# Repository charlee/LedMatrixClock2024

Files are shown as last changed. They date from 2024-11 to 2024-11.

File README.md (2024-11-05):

Led Matrix Clock 2024
=====================

## Hardware

This project is using the ESP32 MH-ET Live MiniKit board.

See [here](https://doc.riot-os.org/group__boards__esp32__mh-et-live-minikit.html) for the pin out of the board.

The hardware is a customized LED display with 3mm blue LEDs. The following diagram shows the layout (Q1..Q4 are the SN74HC595 chips).

```

  o o o o o   o o o o o         o o o o o   o o o o o | 2 \
  o o o o o   o o o o o   o o   o o o o o   o o o o o | 3  |
  o o o o o   o o o o o   o o   o o o o o   o o o o o | 4  |
  o o o o o   o o o o o         o o o o o   o o o o o | 5  | Q4
  o o o o o   o o o o o   o o   o o o o o   o o o o o | 6  |
  o o o o o   o o o o o   o o   o o o o o   o o o o o | 7  |
  o o o o o   o o o o o         o o o o o   o o o o o | 8 /
 -----------------------------------------------------+
  1 2 3 4 5   6 7 8 1 2   3 4   5 6 7 8 1   2 3 4 5 6
  `---------------' `-----------------' `-----------'
        Q1                  Q2                Q3

```

## Schematic

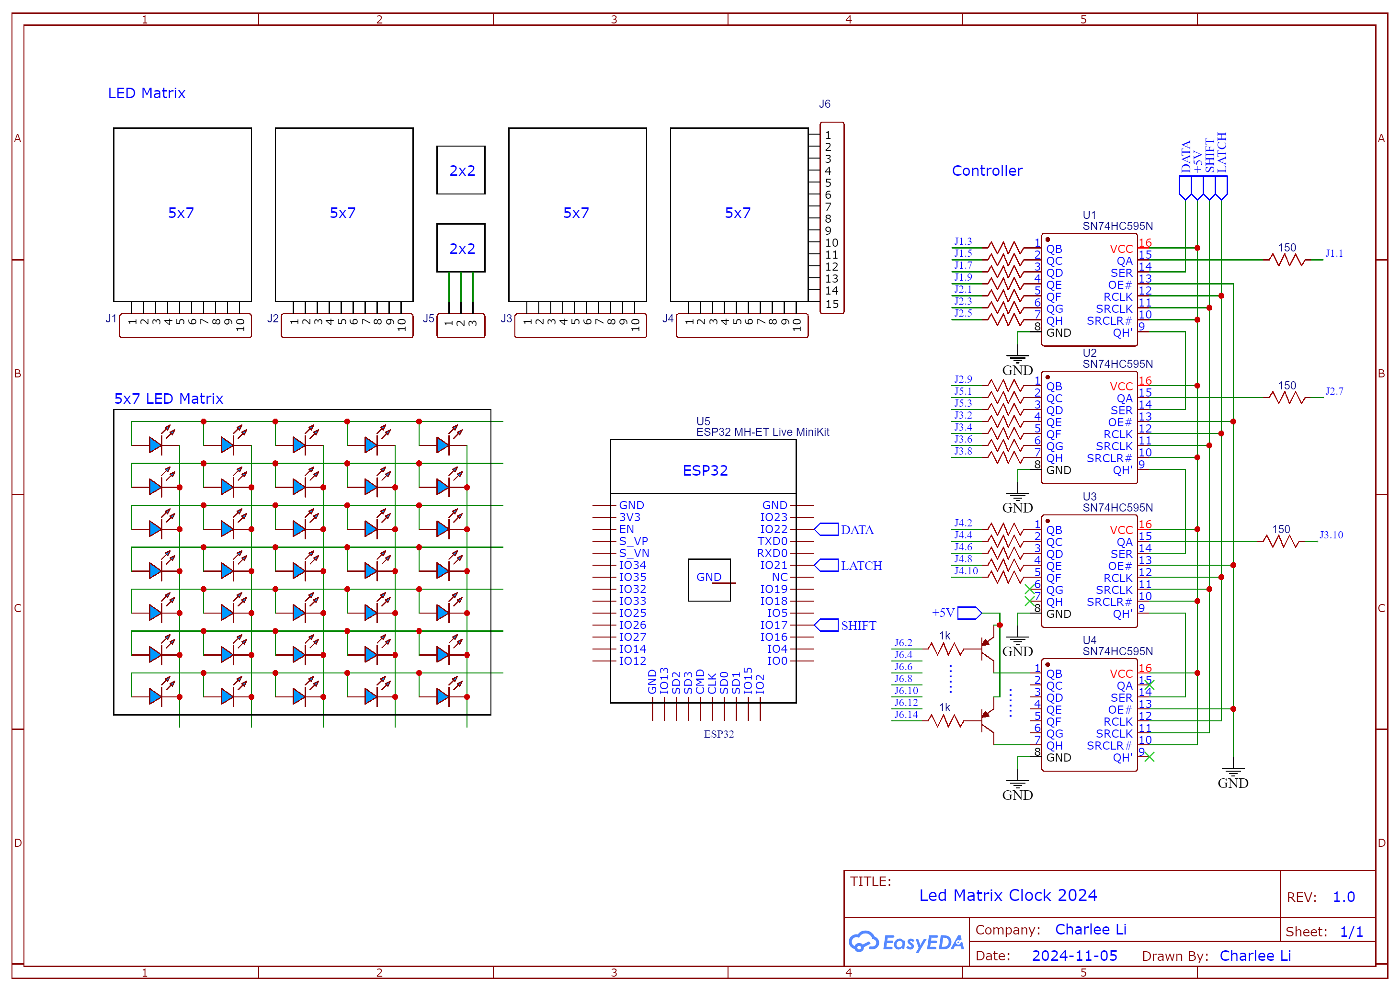
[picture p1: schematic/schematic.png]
Schematic


## Firmware

Install the [esp32 by Espressif Systems, 3.0.5](https://github.com/espressif/arduino-esp32) in the Board Manager of Arduino IDE.
Then choose the "MH ET LIVE ESP32MiniKit" board in the Tools menu.

Fill in the WiFi credentials in the `config.h` file.

The `TIME_SERVER` constant is a Web service that returns the current time in the ISO format `YYYY-MM-DDTHH:MM:SS.uuuuuuuuu+ZZ:ZZ`.

## 3D Printed Case

The case is designed in Autodesk Fusion and printed with a 3D printer.
See [stl](stl) folder for the STL files.

## Assembly

See [assembly](assembly) folder for the assembly instructions.

## Reference

- [ESP32 Timer API](https://docs.espressif.com/projects/arduino-esp32/en/latest/api/timer.html)

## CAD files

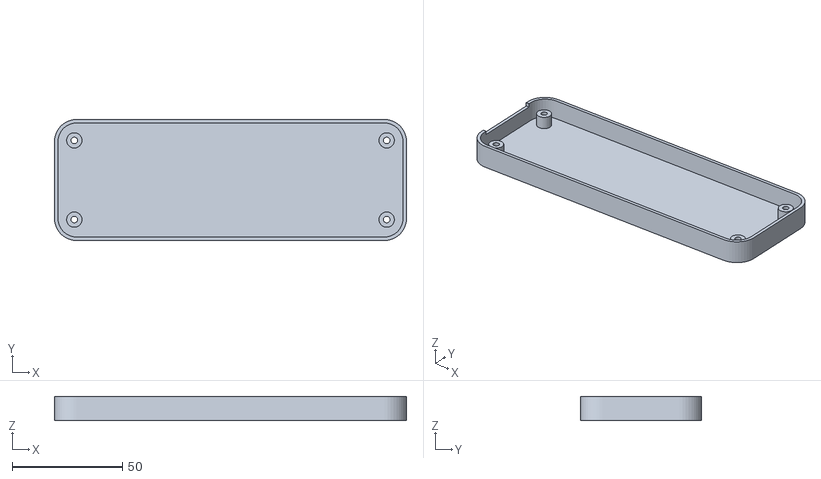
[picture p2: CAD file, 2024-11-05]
stl/ledclock-case-bottom.stl
160.0 x 55.0 x 11.1

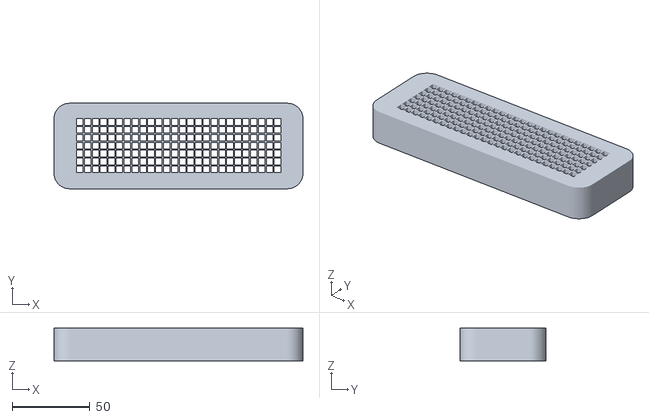
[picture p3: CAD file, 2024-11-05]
stl/ledclock-case-top.stl
160.0 x 55.0 x 21.0

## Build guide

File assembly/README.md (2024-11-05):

Assembly of the LED Matrix Clock
================================

I want to design a digital clock that:

- displays realistic numbers rather than using 7-seg numbers
- displays the time in a 24-hour format
- has a blinking colon to separate the hours and minutes
- is as small as possible
- looks like a commercial product
- auto WiFi time sync

The minimal font size is 5x7 pixels, which is commonly used in LCD 1602 displays.

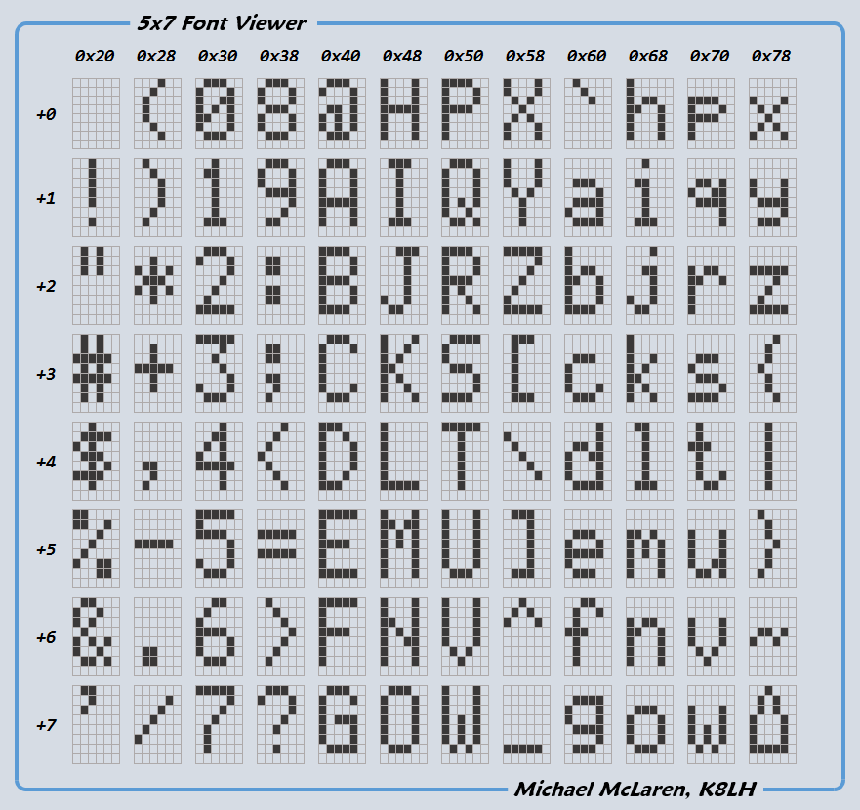
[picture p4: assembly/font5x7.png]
5x7 font


In order to display the time in a 24-hour format, I need 2 digits for the hours and 2 digits for the minutes. The colon is two 2x2 pixel rectangle. That result in four 5x7 matricies and two 2x2 matricies. The layout can be done in the following way to minimize the number of LEDs to be soldered:

```

  o o o o o   o o o o o         o o o o o   o o o o o | 2 \
  o o o o o   o o o o o   o o   o o o o o   o o o o o | 3  |
  o o o o o   o o o o o   o o   o o o o o   o o o o o | 4  |
  o o o o o   o o o o o         o o o o o   o o o o o | 5  | Q4
  o o o o o   o o o o o   o o   o o o o o   o o o o o | 6  |
  o o o o o   o o o o o   o o   o o o o o   o o o o o | 7  |
  o o o o o   o o o o o         o o o o o   o o o o o | 8 /
 -----------------------------------------------------+
  1 2 3 4 5   6 7 8 1 2   3 4   5 6 7 8 1   2 3 4 5 6
  `---------------' `-----------------' `-----------'
        Q1                  Q2                Q3

```

In total this is a 22x7 LED matrix. I will use four SN74HC595 shift registers to control the LEDs, three for the columns and one for the rows.

The microcontroller is an ESP32 MH-ET Live MiniKit board ([pinout](https://doc.riot-os.org/group__boards__esp32__mh-et-live-minikit.html)). The board has a built-in WiFi module to enable WiFi time sync.

The circuit board is built on a 9x15cm perfboard, cutted into two equal pieces. Half of the board is used for the LED matrix and the other half for the SN74HC595 registers and ESP32 board. Two boards can be stacked so that all the invisible parts are hidden behind the LED matrix, to reduce the physical size of the clock.

The board is covered with electic tapes to reduce the glare on the metal pads.

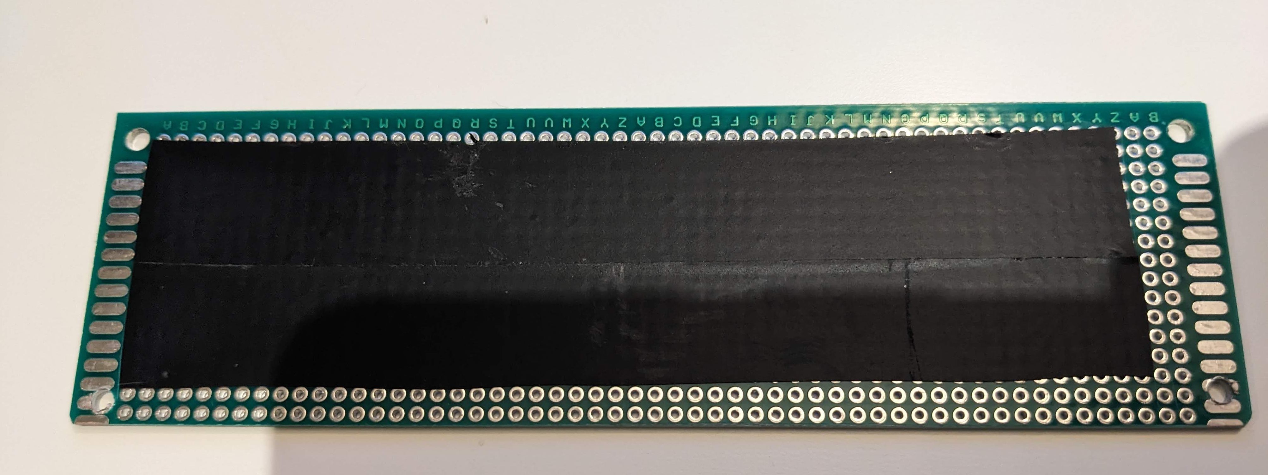
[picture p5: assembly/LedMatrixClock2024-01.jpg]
LED Matrix Clock 01


Then the LEDs are soldered to the board. The LEDs are 3mm blue LEDs. The reason for choosing 3mm rather than 5mm is that 5mm LEDs will leave no space between the LEDs, so it will be impossible to separate the LEDs with a 3D printed grid.

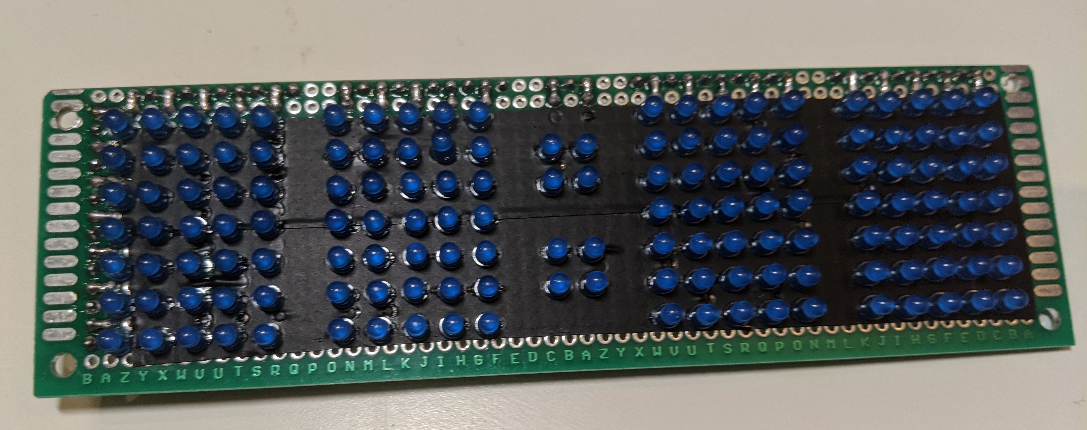
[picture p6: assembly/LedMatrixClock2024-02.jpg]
LED Matrix Clock 02


The cathodes of the LEDs are connected vertically downwards, and the anodes are connected horizontally. Headers are soldered at the edges of the board to connect to the bottom board.

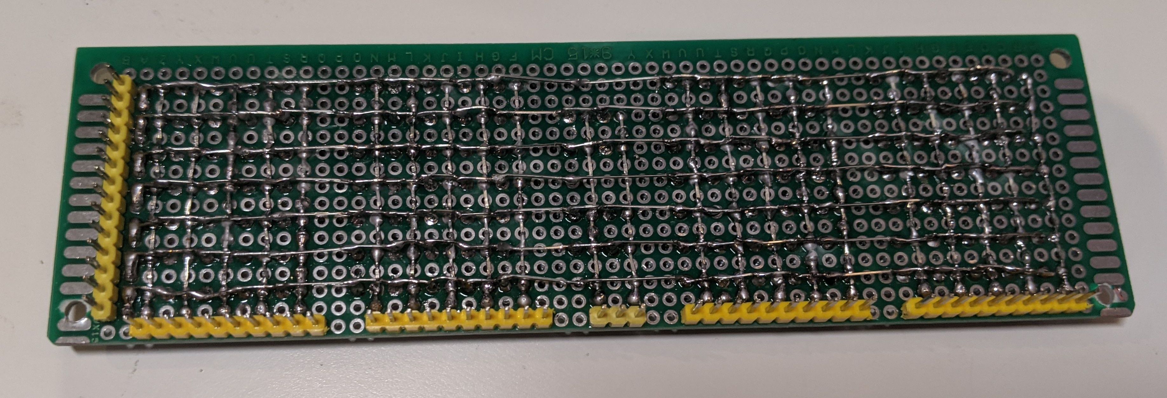
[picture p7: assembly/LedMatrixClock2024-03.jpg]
LED Matrix Clock 03


SN74HC595 registers, ESP32 board, and the necessary resistors and transistors are soldered to the bottom board.

The ESP32 board is soldered directly to the bottom board without using any headers.

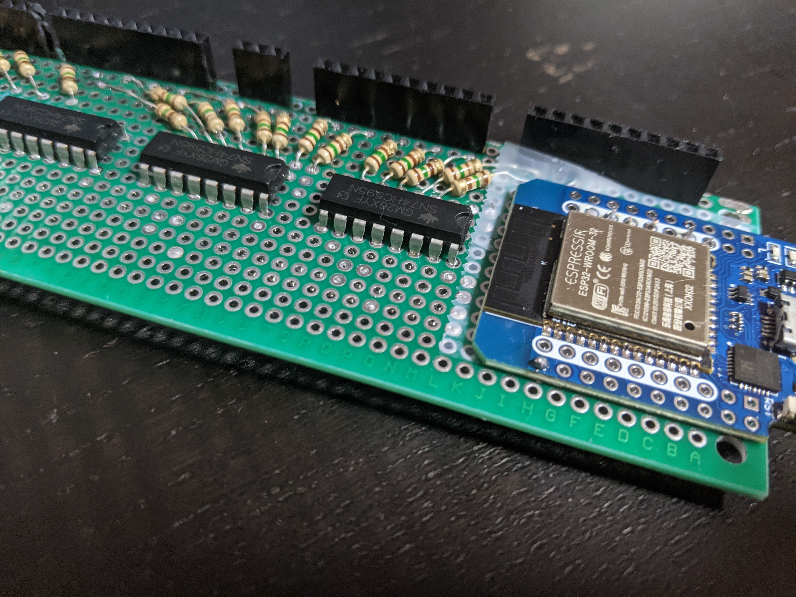
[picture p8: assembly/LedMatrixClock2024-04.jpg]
LED Matrix Clock 04


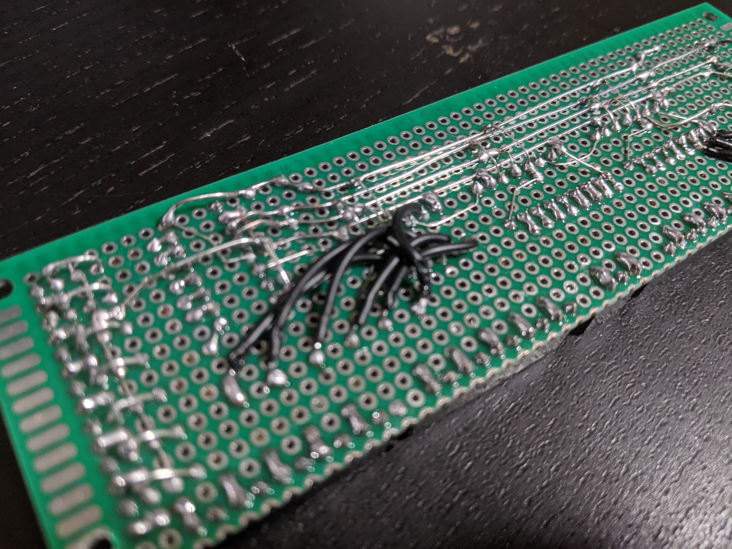
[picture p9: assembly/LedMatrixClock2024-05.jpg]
LED Matrix Clock 05


More pictures of the two boards, and the final assembly:

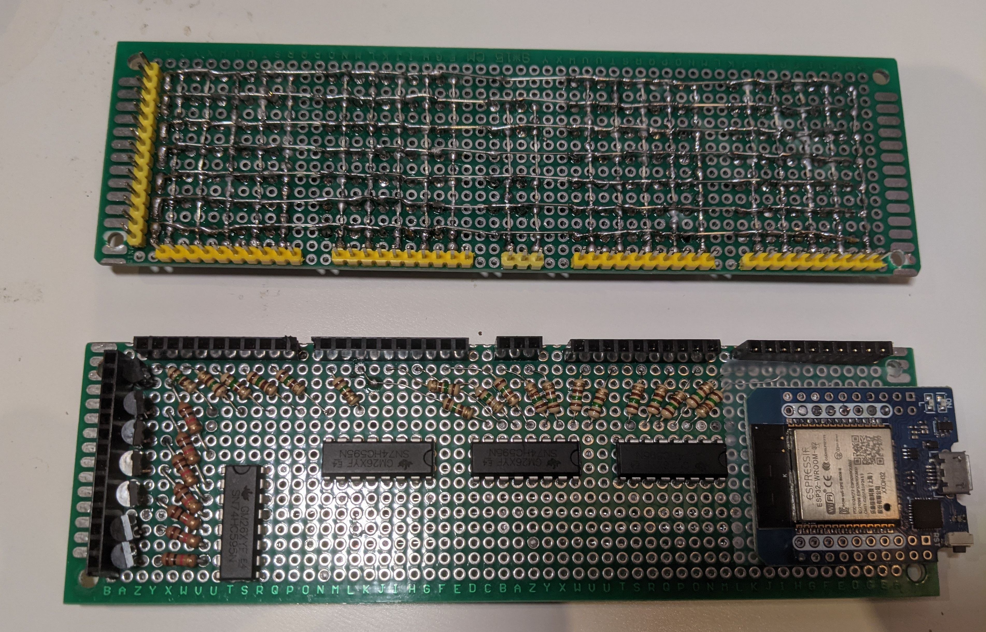
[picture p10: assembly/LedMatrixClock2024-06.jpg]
LED Matrix Clock 06


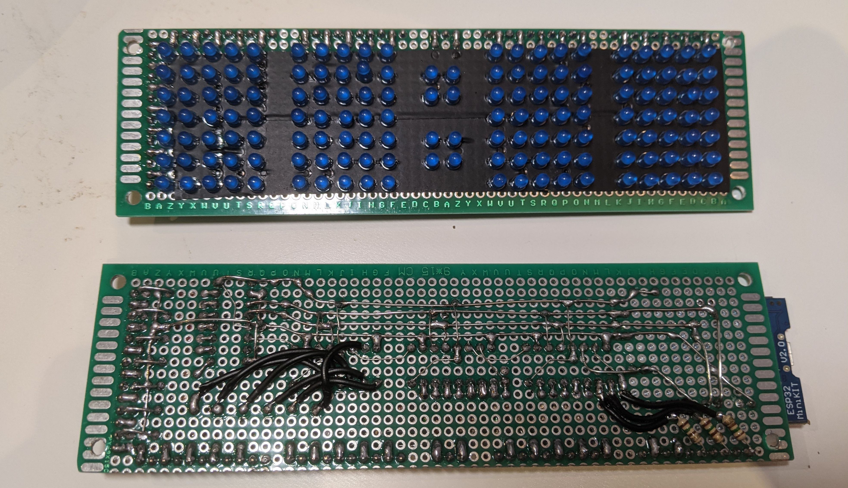
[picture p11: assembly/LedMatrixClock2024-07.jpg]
LED Matrix Clock 07


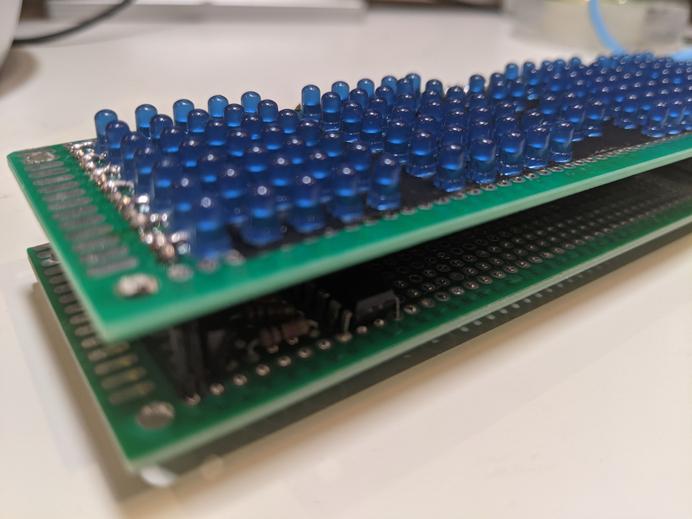
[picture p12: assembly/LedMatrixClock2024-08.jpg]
LED Matrix Clock 08


Upload the firmware and try it out:

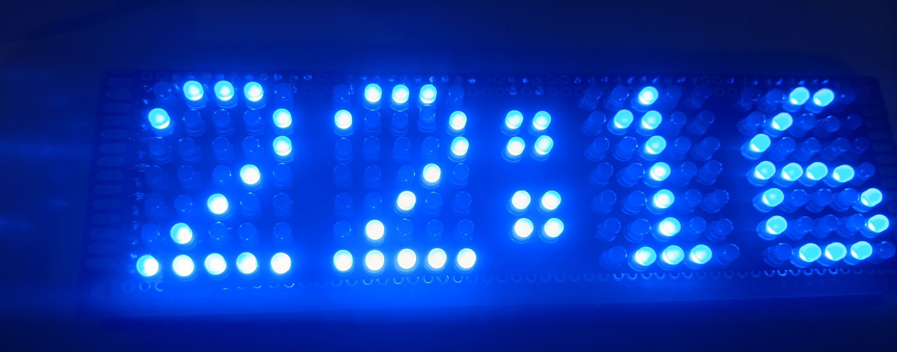
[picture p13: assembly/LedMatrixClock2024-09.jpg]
LED Matrix Clock 09


The case is designed in two parts.

The top part includes a grid to separate the LEDs. The grid is designed to be about 3mm taller than the LEDs to create a space between the front panel and the LEDs. This space will create diffused light.

The top part also includes four holes for the screws.

The bottom part has four through holes so that I can use long screws to hold the two parts together.

Also I need to make some cutouts for the USB port.

_Note: Initially I planned to use snap-fit to hold the two parts together, but a 3D-printed snap-fit is too fragile. Eventually I moved to screws.

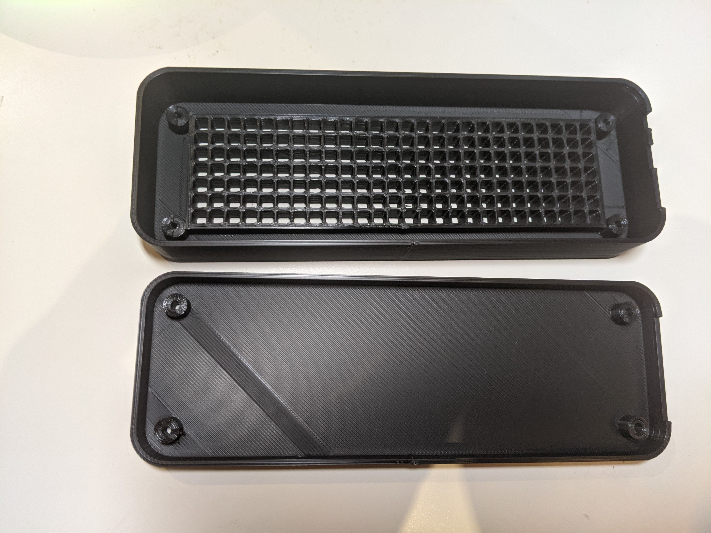
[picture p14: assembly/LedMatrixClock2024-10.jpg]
LED Matrix Clock 10


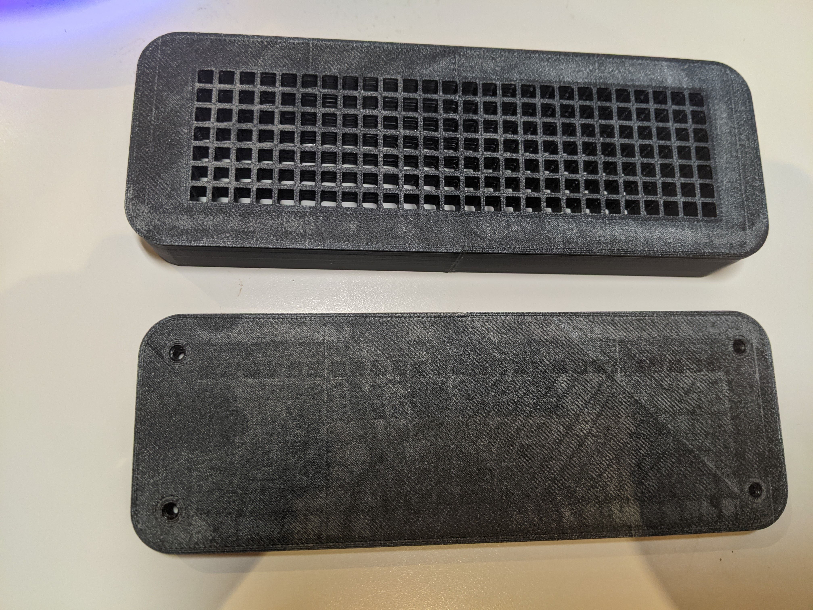
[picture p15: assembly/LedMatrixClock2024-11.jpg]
LED Matrix Clock 11


Install the top board into the top part of the case. Due to some misalignment, I can only use three screws, but this is not a big problem.

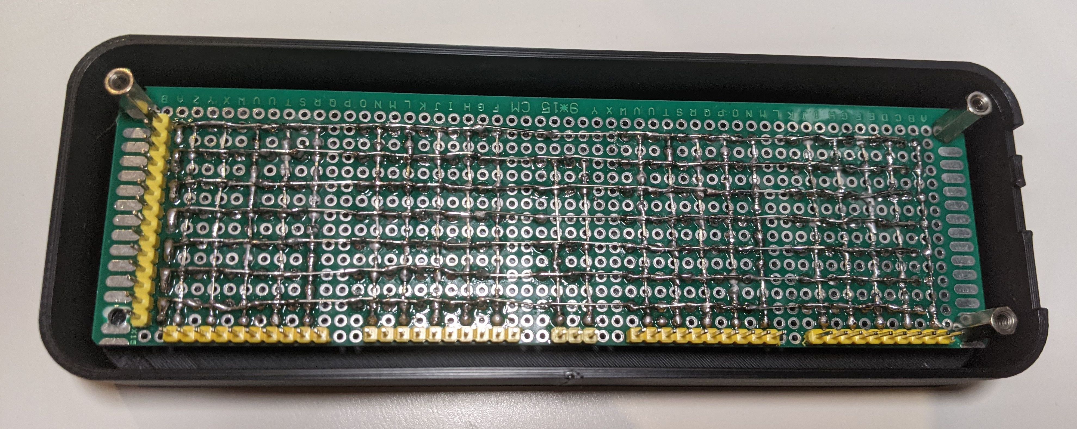
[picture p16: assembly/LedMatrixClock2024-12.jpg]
LED Matrix Clock 12


Attach the bottom board to the top board.

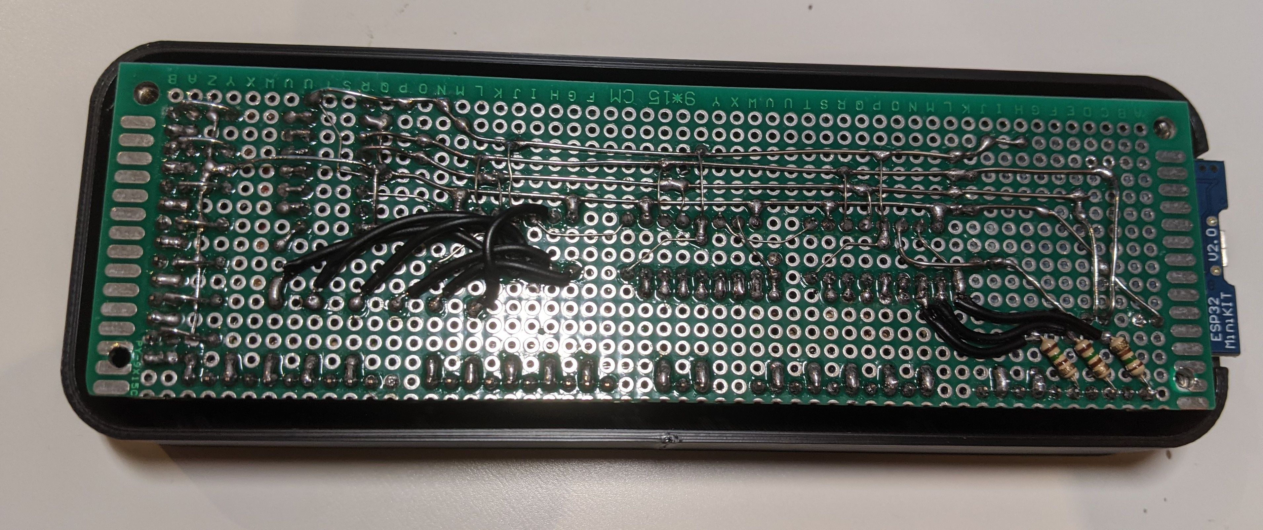
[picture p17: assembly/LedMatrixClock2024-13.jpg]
LED Matrix Clock 13


Enclose the case with the bottom part. Long screws are used to hold the two parts together.

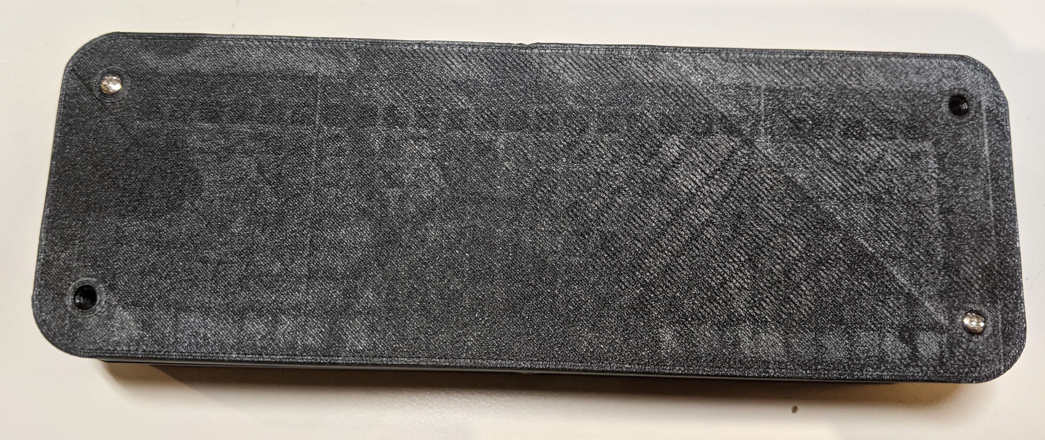
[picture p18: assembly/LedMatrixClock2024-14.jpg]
LED Matrix Clock 14


Power on and try it out. The grid blocked the refraction from other LEDs. The result looks good!

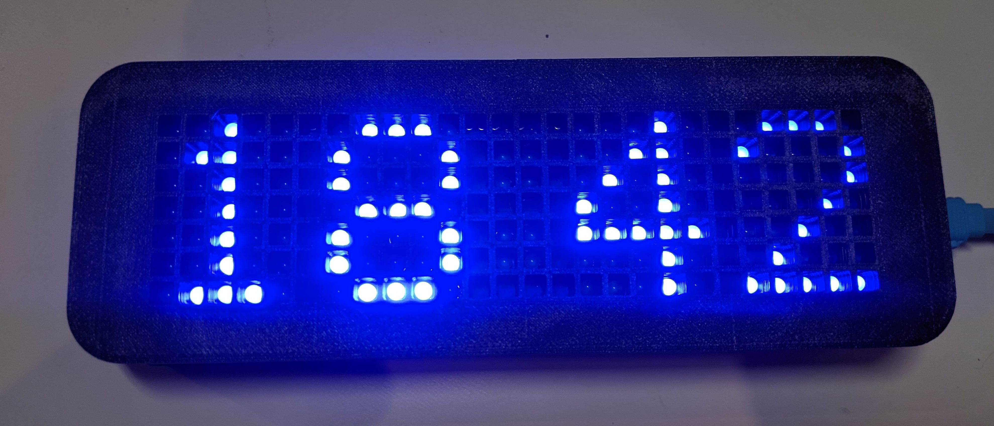
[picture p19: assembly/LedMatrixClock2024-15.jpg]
LED Matrix Clock 15


Now the final piece: a piece of acrylic glass, cutted to the size of the case, one side is sanded to diffuse the light.

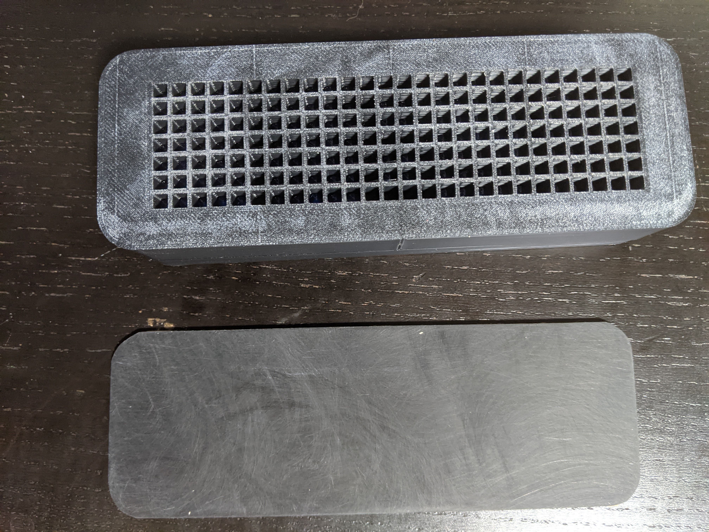
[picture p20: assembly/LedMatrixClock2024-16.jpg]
LED Matrix Clock 16


Glue the acrylic glass to the top part of the case. The final result looks like a commercial product!

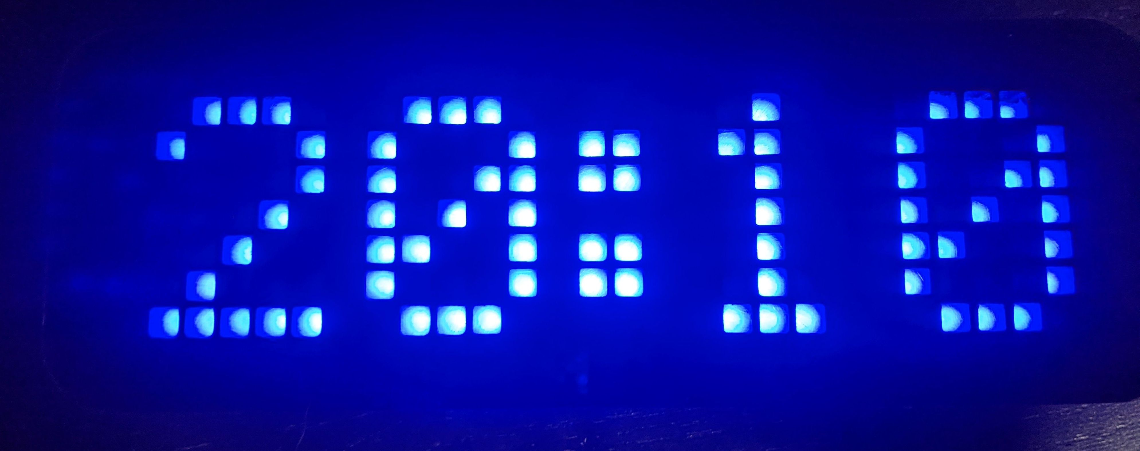
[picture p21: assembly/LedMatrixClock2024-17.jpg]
LED Matrix Clock 17


Final looks on the desk:

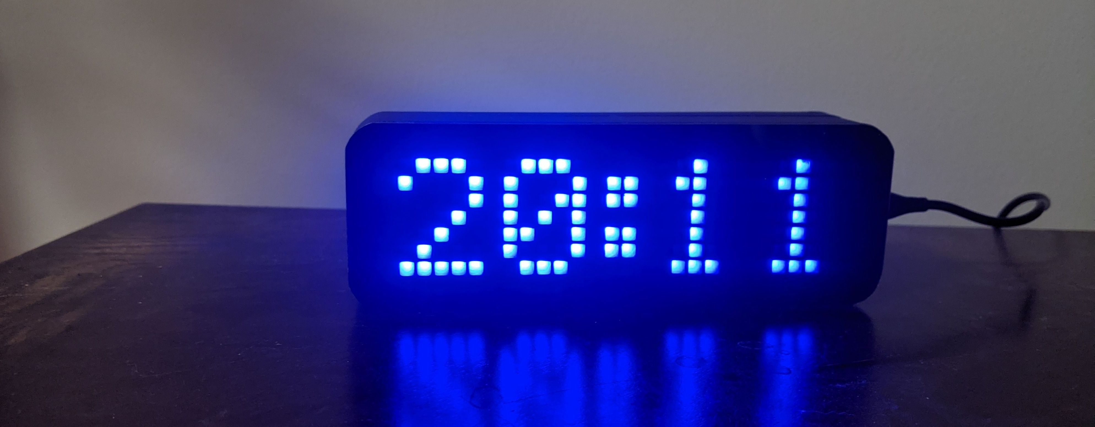
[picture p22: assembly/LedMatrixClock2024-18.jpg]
LED Matrix Clock 18


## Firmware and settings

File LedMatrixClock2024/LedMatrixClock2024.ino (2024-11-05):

#include <WiFi.h>
#include <HTTPClient.h>
#include "include/config.h"
#include "include/font5x7.h"


const char* ssid = WIFI_SSID;
const char* password = WIFI_PASSWORD;


#define read_buf_3bytes(x) (buf[x*3] << 16 | buf[x*3 + 1] << 8 | buf[x*3 + 2])
#define write_buf_3bytes(x, v) (buf[x*3] = (v >> 16) & 0xff, buf[x*3 + 1] = (v >> 8) & 0xff, buf[x*3 + 2] = v & 0xff)

unsigned long lastSyncMillis = 0;  
const long interval = 24 * 60 * 60 * 1000;  // sync time every 24 hours

// buf for display
uint8_t buf[21] = {0};

/*******************************************************************************
 * 74HC595 control
 */

#define DATA_PIN 22
#define LATCH_PIN 21
#define CLOCK_PIN 17

// Send 4 bytes to SN74HC595
void send_data_sn74hc595(uint32_t data) {
  digitalWrite(LATCH_PIN, LOW);
  
  // since the row register is the furthest, we need to send the data in reverse order
  for (int i = 31; i >= 0; i--) {
    digitalWrite(CLOCK_PIN, LOW);
    digitalWrite(DATA_PIN, (data & (1 << i)) ? HIGH : LOW);
    digitalWrite(CLOCK_PIN, HIGH);
  }

  digitalWrite(LATCH_PIN, HIGH);
}

void send_line(int line) {
  uint32_t data = buf[line * 3] << 16 | buf[line * 3 + 1] << 8 | buf[line * 3 + 2];
  uint32_t pos = (~(1 << (line + 1)) << 24) & 0xff000000;
  data = (~data & 0xffffff) | pos;
  send_data_sn74hc595(data);
}


/*******************************************************************************
 * Timer
 */
hw_timer_t *timer = NULL;
volatile uint32_t lineno = 0;

void ARDUINO_ISR_ATTR onTimer() {
  send_line(lineno);
  lineno++;
  if (lineno >= 7) {
    lineno = 0;
  }
}

void setup() {
  Serial.begin(115200);
  delay(10);
  
  // setup PIN mode
  pinMode(DATA_PIN, OUTPUT);
  pinMode(LATCH_PIN, OUTPUT);
  pinMode(CLOCK_PIN, OUTPUT);

  // start timer
  timer = timerBegin(1000000);
  timerAttachInterrupt(timer, &onTimer);
  timerAlarm(timer, 1000, true, 0);
  
  // Connect to WiFi
  Serial.println();
  Serial.println();
  Serial.print("Connecting to ");
  Serial.println(ssid);

  WiFi.begin(ssid, password);

  while (WiFi.status() != WL_CONNECTED) {
    delay(500);
    Serial.print(".");
  }

  Serial.println("");
  Serial.println("WiFi connected");
  Serial.println("IP address: ");
  Serial.println(WiFi.localIP());
}

int day;
int hour;
int minute;
int second;
int millisec;
int lastMillisec = 0;

unsigned lastCalcMillis = 0;


/*******************************************************************************
 * Display control
 */
void show_digit(int digit, int pos) {
  uint32_t offset, v, mask, new_v, buf_v;

  // find from which bit to draw 
  offset = pos * 5;
  if (pos > 1) {

    // if high digits, then offset the colon
    offset += 2;
  }

  // draw digit
  for (int i = 0; i < 7; i++) {

    buf_v = read_buf_3bytes(i);
    v = FONT5x7[digit * 7 + i] << offset;
    mask = ~(0b11111 << offset);
    new_v = (buf_v & mask) | v;

    // write back
    write_buf_3bytes(i, new_v);
  }
}

void show_colon(bool show) {
  uint32_t v, mask, new_v, buf_v;
  for (int i = 0; i < 7; i++) {
    buf_v = read_buf_3bytes(i);

    v = COLON[i] << 10;
    mask = ~(0b11 << 10);
    if (show) {
      new_v = (buf_v & mask) | v;
    } else {
      new_v = buf_v & mask;
    }
    
    // write back
    write_buf_3bytes(i, new_v);
  }
}

void show_clock(int hour, int minute, int millisec) {
    int digit = 0;

    digit = minute % 10;
    show_digit(digit, 0);
    
    digit = minute / 10;
    show_digit(digit, 1);

    digit = hour % 10;
    show_digit(digit, 2);

    digit = hour / 10;
    if (digit == 0) {
      show_digit(DIGIT_SPACE, 3);
    } else {
      show_digit(digit, 3);
    }
    
    if (millisec > 500) {
      show_colon(true);
    } else {
      show_colon(false);
    }
}

void show_error(int errcode) {
  show_digit(errcode % 10, 0);
  show_digit((errcode / 10) % 10, 1);
  show_digit(DIGIT_DASH, 2);
  show_digit(DIGIT_E, 3);
}

void show_init() {
  show_digit(DIGIT_DASH, 0);
  show_digit(DIGIT_DASH, 1);
  show_digit(DIGIT_DASH, 2);
  show_digit(DIGIT_DASH, 3);
}

// for debug purpose
void print_buf() {
  uint32_t buf_v;
  for (int i = 0; i < 7; i++) {
    buf_v = read_buf_3bytes(i);
    for (int j = 21; j >= 0; j--) {
      Serial.print((buf_v & (1 << j)) ? "x" : ".");
      if (j == 17 || j == 12 || j == 10 || j == 5) {
        Serial.print(" ");
      }
    }
    Serial.println();
  }
  Serial.println();
}

void loop() {
  unsigned long currentMillis = millis();
  

  if (currentMillis - lastSyncMillis >= interval || lastSyncMillis == 0) {
    Serial.println("Syncing local time...");
    
    show_init();
  
    // sync time with server
    if (WiFi.status() == WL_CONNECTED) {
      WiFiClient client;
      HTTPClient http;
      Serial.println("WIFI connected, calling API...");

      http.begin(client, TIME_SERVER);
      int httpCode = http.GET();
      
      Serial.println(httpCode);

      if (httpCode == 200) {
        String payload = http.getString();
        Serial.print("Local time service response: ");
        Serial.println(payload);
        // Here you can add the code to sync your local clock
        
        day = payload.substring(8, 10).toInt();
        hour = payload.substring(11, 13).toInt();
        minute = payload.substring(14, 16).toInt();
        second = payload.substring(17, 19).toInt();
        millisec = payload.substring(20, 23).toInt();
        
        // confirm that the sync is successful
        lastSyncMillis = currentMillis;
        
        lastCalcMillis = millis();
      } else {
        // otherwise, wait for 10 seconds before retrying
        show_init();
        Serial.println("Failed to sync local time, server response:");
        Serial.println(httpCode);
        Serial.println("retrying in 10 seconds...");
        show_error(2);
        delay(10000);
      }

      http.end();
    } else {
      // if wifi is not connected, wait for 10 seconds before retrying
      // show_wifi(CRGB::Red);
      Serial.println("WIFI not connected, retrying in 10 seconds...");
      show_error(1);
      delay(10000);
    }
  }
  
  // record last millisec to reduce rendering
  lastMillisec = millisec;
    
  // update time
  currentMillis = millis();
  unsigned long diff = currentMillis - lastCalcMillis;
  millisec += diff;

  
  if (millisec >= 1000) {
    second += millisec / 1000;
    millisec %= 1000;
  }

  if (second >= 60) {
    second -= 60;
    minute++;
  }

  if (minute >= 60) {
    minute -= 60;
    hour++;
  }

  if (hour >= 24) {
    hour -= 24;
  }
  
  
  // update state counter
  lastCalcMillis = currentMillis;

  // only update display when millisec changes
  if (lastMillisec >= 500 && millisec < 500 || lastMillisec < 500 && millisec >= 500) {
    // show time
    show_clock(hour, minute, millisec);
  }
  
  delay(100);
}

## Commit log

2024-11-05 added error display; added docs
    [ledclock-case-bottom.stl, ledclock-case-top.stl]
2024-11-05 added assembly instruction
